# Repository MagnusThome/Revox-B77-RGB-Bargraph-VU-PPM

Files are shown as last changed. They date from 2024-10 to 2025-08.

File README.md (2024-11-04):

# Replacement LED bargraph VU & PPM for Revox B77
### "Full RGB" LED display that can show either VU, PPM or VU+PPM simultaneously

I bought myself an old Revox B77 that needed some fixing. Mainly as a fun project, I have always wanted a two track high speed B77. Among other things the left VU meter was broken. The spool winding in it was broken and despite my best efforts I just couldn't get a hold of the tail end of the extemely thin spool wire to re-attach it. So looking around on the internet for an oem spare part VU meter I found that they have been out of production for a while and the prices have sky rocketed. With shipping and VAT just one meter would cost me $250. And since it was said that, in worst case, they can differ ever so slightly in color and look, there was a small risk that I would need to buy two. So I decided why not have a bit of fun instead designing some pcb with schematics and code, as yet another hobby project!  

All files are here on GitHub for you to order an empty pcb, solder paste stencil, the front panel (which also is just a regular pcb) and the electronic parts for you to assemble, solder and load the code on to. If soldering surface mount parts isn't your thing you can always check with me if I happen to have an extra spare board or two, this is me: magnust@gmail.com

&nbsp;
## Original vs LED bar, matching levels and VU ballistics (YouTube video)


## Showing some color modes (YouTube video)


&nbsp;
## Programming mode, changing colors, display mode and "screen saver"
  
### Change display colors
First long press the front panel button __once__ and then toggle through all the color schemes with short presses. To save your choice long press again. 
  
### Change display brightness
First long press the front panel button __twice__ and then toggle through the different brightness levels with short presses. To save your choice long press again. 
  
### Change display mode
First long press the button __three__ times and then toggle through the below modes with short presses, preferably with music playing so you can differ between the modes. To save your choice long press once again. Display modes available are:
- VU (dot)
- VU (bar)
- PPM (dot)
- PPM (bar)
- VU (bar) and PPM (dot)

### Change "screen saver"
First long press the button __four__ times and then toggle through any available screen savers. After each short press the current choice will be shown for two seconds. The "screen saver OFF" option will just show the normal meter. To save your choice long press once again.
And yeah, it is not a screen saver in the real sense of the word, it's just some fun color schemes that can be activated when there has been no input signal for a while.
  
### Leaving programming mode  
There is a timeout when in programming mode, if no button is pressed at all for 15 seconds the screen will blink once and you will be back in normal mode. If you haven't long pressed to save your current choice any change will be ignored.

&nbsp;
## Correct frequency response
YouTube videos:  
 

&nbsp;
## Some examples of color and display modes:
In the pictures below the display is in program mode (shown by a white LED being turned on in the lower part of left display). Different color schemes are easily added, some distinct and some more oddball color schemes are already in the code.
  
### VU (dot)
 

### VU (bar) and PPM (dot)


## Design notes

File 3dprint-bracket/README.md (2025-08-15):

# 3D printed fastening bracket

3D print bracket

PXL_20241112_165132203-EDIT





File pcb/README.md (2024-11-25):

# Main pcb





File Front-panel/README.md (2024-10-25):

# Front panel

I use a dark transparent film glued between two identical panel board pcbs as a front panel. The panels are just normally manufactured pcbs that have a printed top silk screen, black solder mask and the rectangular cut outs.

panel1
panel2

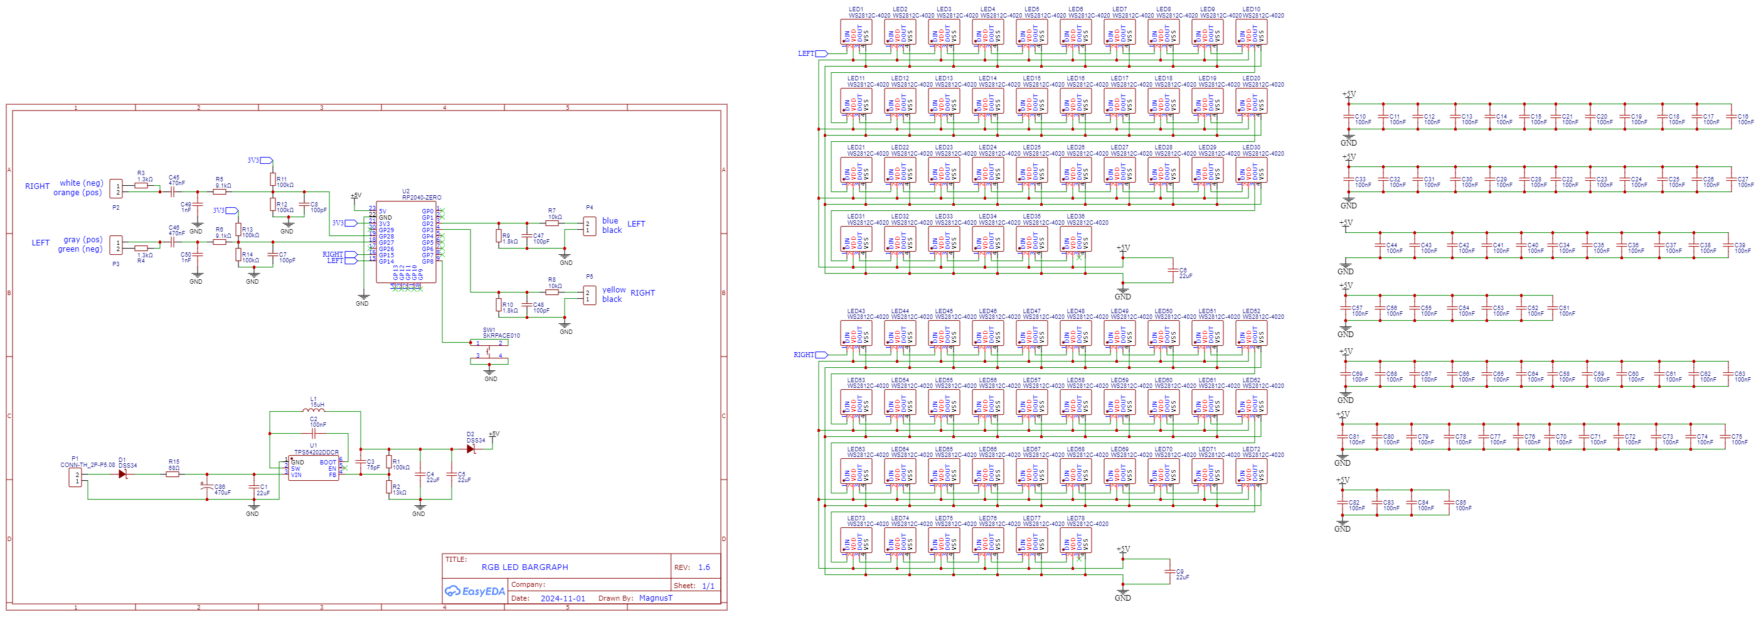
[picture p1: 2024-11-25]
pcb/Schematic_LED-bargraph-1.7_2024-11-25.png

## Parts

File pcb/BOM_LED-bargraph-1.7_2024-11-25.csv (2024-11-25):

ID | Name | Designator | Footprint | Quantity | Manufacturer Part | Manufacturer | Supplier | Supplier Part
1 | 470uF | C86 | CAP-SMD_BD6.3-L6.6-W6.6-FD | 1 | RVT1A471M0607 | ROQANG(容强) | LCSC | C335982
2 | 68Ω | R15 | R2512 | 1 | 25121WJ0680T4E | UNI-ROYAL(厚声) | LCSC | C25492
3 | WS2812C-4020 | LED1,LED2,LED3,LED4,LED5,LED6,LED7,LED8,LED9,LED10,LED11,LED12,LED13,LED14,LED15,LED16,LED17,LED18,LED19,LED20,LED21,LED22,LED23,LED24,LED25,LED26,LED27,LED28,LED29,LED30,LED31,LED32,LED33,LED34,LED35,LED36,LED43,LED44,LED45,LED46,LED47,LED48,LED49,LED50,LED51,LED52,LED53,LED54,LED55,LED56,LED57,LED58,LED59,LED60,LED61,LED62,LED63,LED64,LED65,LED66,LED67,LED68,LED69,LED70,LED71,LED72,LED73,LED74,LED75,LED76,LED77,LED78 | LED-SMD_4P-L4.0-W1.7-R | 72 | WS2812C-4020 | worldsemi | LCSC | C4154870
4 | SKRPACE010 | SW1 | KEY-SMD_4P-L4.2-W3.2-P2.20-LS4.6 | 1 | SKRPACE010 | ALPSALPINE(阿尔卑斯阿尔派) | LCSC | C139797
5 | 1nF | C49,C50 | C0603 | 2 | CL10C102JB8NNNC | SAMSUNG(三星) | LCSC | C163508
6 | 100pF | C7,C8,C47,C48 | C0603 | 4 | CL10C101JB8NNNC | SAMSUNG(三星) | LCSC | C14858
7 | 470nF | C45,C46 | C0805 | 2 | CL21B474KBFNNNE | SAMSUNG(三星) | LCSC | C13967
8 | 1.3kΩ | R3,R4 | R0603 | 2 | 0603WAF1301T5E | UNI-ROYAL(厚声) | LCSC | C22767
9 | 9.1kΩ | R5,R6 | R0603 | 2 | 0603WAF9101T5E | UNI-ROYAL(厚声) | LCSC | C23260
10 | 10kΩ | R7,R8 | R0603 | 2 | 0603WAF1002T5E | UNI-ROYAL(厚声) | LCSC | C25804
11 | 1.8kΩ | R9,R10 | R0603 | 2 | 0603WAF1801T5E | UNI-ROYAL(厚声) | LCSC | C4177
12 | 100kΩ | R11,R12,R13,R14,R1 | R0603 | 5 | 0603WAF1003T5E | UNI-ROYAL(厚声) | LCSC | C25803
13 | 22uF | C9,C6,C4,C5 | C0603 | 4 | CL10A226MQ8NRNC | SAMSUNG | LCSC | C59461
14 | 100nF | C10,C11,C12,C13,C14,C15,C16,C17,C18,C19,C20,C21,C22,C23,C24,C25,C26,C27,C28,C29,C30,C31,C32,C33,C34,C35,C36,C37,C38,C39,C40,C41,C42,C43,C44,C85,C84,C83,C82,C81,C80,C79,C78,C77,C76,C75,C74,C73,C72,C71,C70,C69,C68,C67,C66,C65,C64,C63,C62,C61,C60,C59,C58,C57,C56,C55,C54,C53,C52,C51,C2 | C0402 | 71 | CL05B104KO5NNNC | SAMSUNG(三星) | LCSC | C1525
15 | RP2040-ZERO | U2 | COMM-SMD_RP2040-ZERO | 1 | RP2040-Zero | Waveshare(微雪电子) | LCSC | C5350143
16 | DSS34 | D1,D2 | SOD-123_L2.8-W1.8-LS3.7-RD | 2 | DSS34 | STARSEA | LCSC | C84632
17 | TPS54202DDCR | U1 | SOT-23-6_L2.9-W1.6-P0.95-LS2.8-BL | 1 | TPS54202DDCR | TI(德州仪器) | LCSC | C191884
18 | 22uF | C1 | C0805 | 1 | CL21A226MAYNNNE | Samsung Electro-Mechanics | LCSC | C602037
19 | 15uH | L1 | IND-SMD_L6.0-W6.0_CDRH5D18BHPNP | 1 | SLP6028S150MTT | Sunltech(韩国顺磁) | LCSC | C254863
20 | 75pF | C3 | C0603 | 1 | CC0603JRNPO9BN750 | YAGEO(国巨) | LCSC | C282074
21 | 13kΩ | R2 | R0603 | 1 | 0603WAF1302T5E | UNI-ROYAL(厚声) | LCSC | C22797

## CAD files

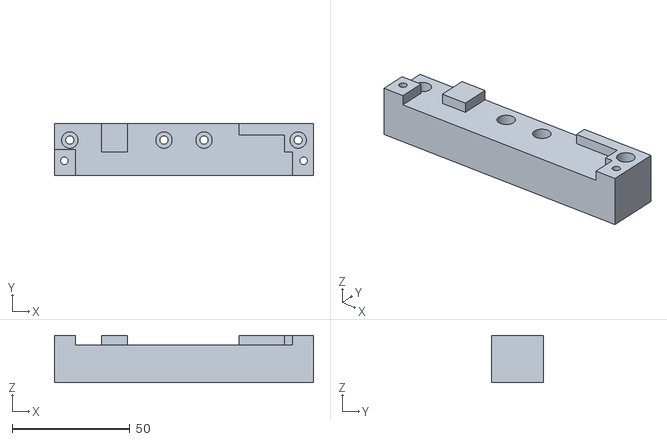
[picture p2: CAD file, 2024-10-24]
3dprint-bracket/3D print bracket.stl
110.0 x 22.0 x 20.0

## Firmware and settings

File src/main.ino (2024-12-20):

#include <Arduino.h>
#include <JC_Button.h>
#include "measurement.h"
#include "display.h"
#include "overdrivelamp.h"

#define DEBUG

#define NUMCHANNELS 2
#define L 0
#define R 1

#define BUTTONGPIO 8
#define LONG_PRESS 500
#define PROGRAMMODETIMEOUT 15 // seconds
Button myBtn(BUTTONGPIO);
uint8_t programmode = 0;
float level[3][NUMCHANNELS];


void setup() {
#ifdef DEBUG
  delay(200);
  Serial.begin(115200);
  delay(200);
  Serial.println("Boot VU meter");
#endif
  pinMode(BUTTONGPIO, INPUT_PULLUP);
  myBtn.begin();
  geteeprom();
  begindisplay();
  beginoverdrivelamp();
  startadc();
  findDcBias(1);
}


void loop() {
  unsigned long loopnow = millis();
  sampleAudio();
  
  static unsigned long displaytimer;
  if (loopnow - displaytimer >= 1000/12 ) {  
    displaytimer = loopnow;
    refreshAVG();
    refreshRMS();
    refreshPPM();
    for (uint8_t ch=0;ch<NUMCHANNELS;ch++) {
      level[AVG][ch] = avgBallistics(ch);
      level[RMS][ch] = rmsBallistics(ch);
      level[PPM][ch] = ppmBallistics(ch);
     }
    //if (detectOverdrive(L) || detectOverdrive(R)) { do something }
    //else { or something else }
    if ( !screensaver(SCRSAVERAUTO, level[RMS][L]+level[RMS][R]) ) {
      updateLeds(level[RMS][L], level[RMS][R], level[PPM][L], level[PPM][R]);
    }
    checkbutton();
    showmodenumber(programmode);
  }

  #ifdef DEBUG
  static unsigned long printtimer;
  if (loopnow - printtimer >= 1000/PRINTFREQ ) {  
    printtimer = loopnow;
    //debugMeasurement();
    Serial.printf("     %6.0f %6.0f %6.0f", level[AVG][L], level[RMS][L], level[PPM][L] );
    Serial.printf("     %6.0f %6.0f %6.0f", level[AVG][R], level[RMS][R], level[PPM][R] );
    //Serial.printf("      %2ld ms", (millis()-loopnow) );
    Serial.printf("\n0");
  }
  #endif
}


void checkbutton(void) {
  static bool prevWasLong = false;
  unsigned long loopnow = millis();
  #define MAXPROGRAMMODES 4
  
  static unsigned long buttontimeout;
  if (  programmode>0  &&  loopnow-buttontimeout>=PROGRAMMODETIMEOUT*1000  ) {  
    flashleds(0x333333);
    programmode = 0;
    delay(200);
  }

  myBtn.read();
  if (myBtn.wasReleased() && prevWasLong) {
    prevWasLong = false;
  }
  else if (myBtn.wasReleased()) {
    buttontimeout = loopnow;
    switch (programmode) {
      case 0:
        break;
      case 1:
        changecolor();
        break;
      case 2:
        changedimmer();
        break;
      case 3:
        changedisplmode();
        break;
      case 4:
        changescrsv();
        break;
      default:
        programmode = 0;
    }
  }
  
  if (myBtn.pressedFor(LONG_PRESS) && !prevWasLong) {
    prevWasLong = true;
    buttontimeout = loopnow;
    showmodenumber(programmode);
    programmode++;
    if(programmode) {
      showmodenumber(programmode);
      screensaver(SCRSAVEREND);  // just one single call to end screensaver if active
    }
    if(programmode>1) {
      stopadc();
      savetoeeprom();
      startadc();
      findDcBias();
    }
    if (programmode>MAXPROGRAMMODES) programmode = 0;
  }
}

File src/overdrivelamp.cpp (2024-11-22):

#include "overdrivelamp.h"


#define OVRINPUTGPIO_L  2
#define OVRINPUTGPIO_R  3

#define L 0
#define R 1

uint8_t channelgpio[] = {OVRINPUTGPIO_L, OVRINPUTGPIO_R};


// -------------------------------------------------------------------------------------

void beginoverdrivelamp(void) {
  pinMode(OVRINPUTGPIO_L, INPUT);
  pinMode(OVRINPUTGPIO_R, INPUT);
}


bool detectOverdrive(uint8_t ch) {
  return digitalRead(channelgpio[ch]);
}

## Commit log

2024-11-01 pcb v1.6 added filter
    two caps filter added
    [BOM_LED-bargraph-1.5_2024-10-24.csv, BOM_LED-bargraph-1.6_2024-11-01.csv, Sheet_1_2024-10-24.schdoc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]
2024-11-01 v1.6
    No changes from v1.5. Just keeping version number in sync with main board
2024-11-07 measure int vs uint8 errors
    [main.ino, measurement.cpp]
2024-11-07 uint vs int errors
    [display.cpp, main.ino, measurement.cpp]
2024-11-12 new pics of mounting the display
2024-11-24 flush adc at startup
2024-11-25 input pwr filter
    [BOM_LED-bargraph-1.6_2024-11-01.csv, BOM_LED-bargraph-1.7_2024-11-25.csv, PickAndPlace_PCB_LED-bargraph_2024-11-25.csv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]
2024-12-05 calibrate steps
2024-12-10 tweak ppm noise gate
    [display.cpp, main.ino, measurement.cpp]
